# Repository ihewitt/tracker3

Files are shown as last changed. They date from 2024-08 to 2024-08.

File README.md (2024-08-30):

# Tracker III.2
A BG96 and NRF52840 based GPS tracker

The history for this design can be found on a series of posts: [Tracking running](https://blog.ivor.org/2020/10/tracking-running-part-2.html) [RAK track](https://blog.ivor.org/2022/02/between-rak-and-sweet-place.html) [Tracker two](https://blog.ivor.org/2022/03/trackertwo.html), the full details for this build are at [T3 Rise of the machines](https://blog.ivor.org/2024/08/t3-rise-of-machines.html)

Latest schematic [here](schematic.pdf), component layout [here](layout.pdf), Bill of materials [here](tracker-bom.csv)

Main functional features on the board are highlighted here:

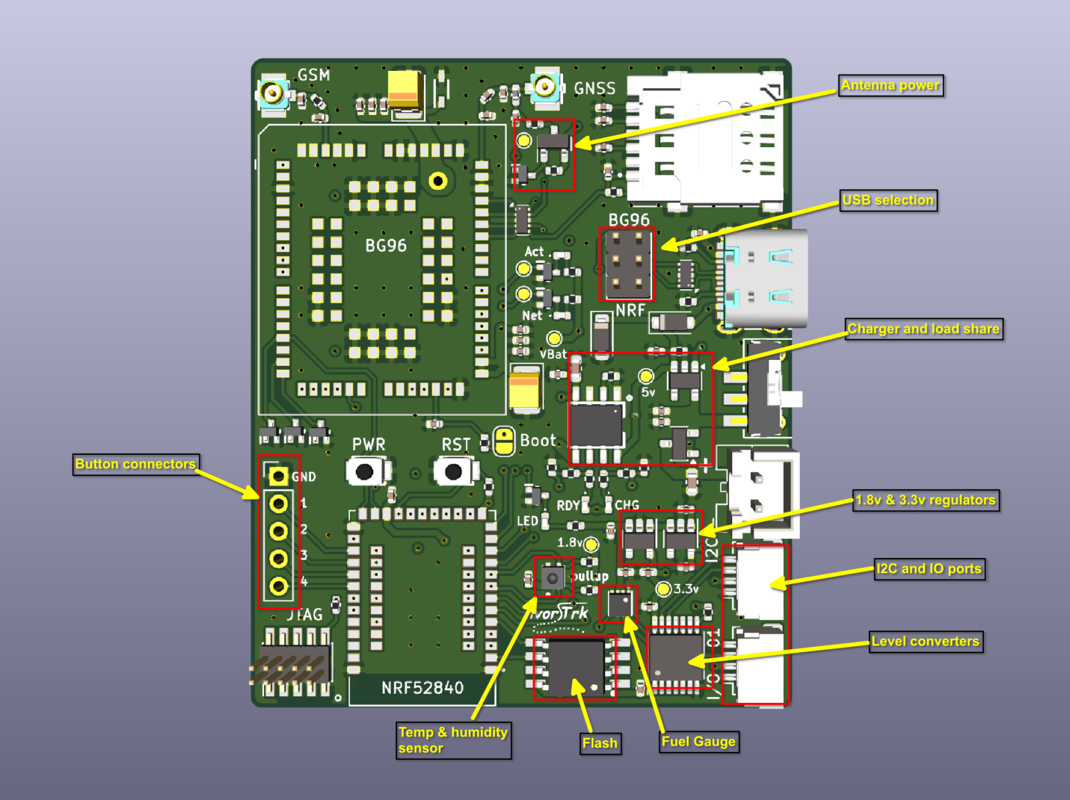
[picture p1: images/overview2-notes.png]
New PCB design


### USB connection
I changed to a USB-C connector, and the USB connection can be switched between the NRF and BG96 chips, most of the time the NRF will be useful but if you need/want to diagnose the GPS data directly or update the BG96 firmware then you can move jumpers.

### Charger
I changed the charger design to include a load share design and a power regulator with a "reverse current" protection shown on the schematic:

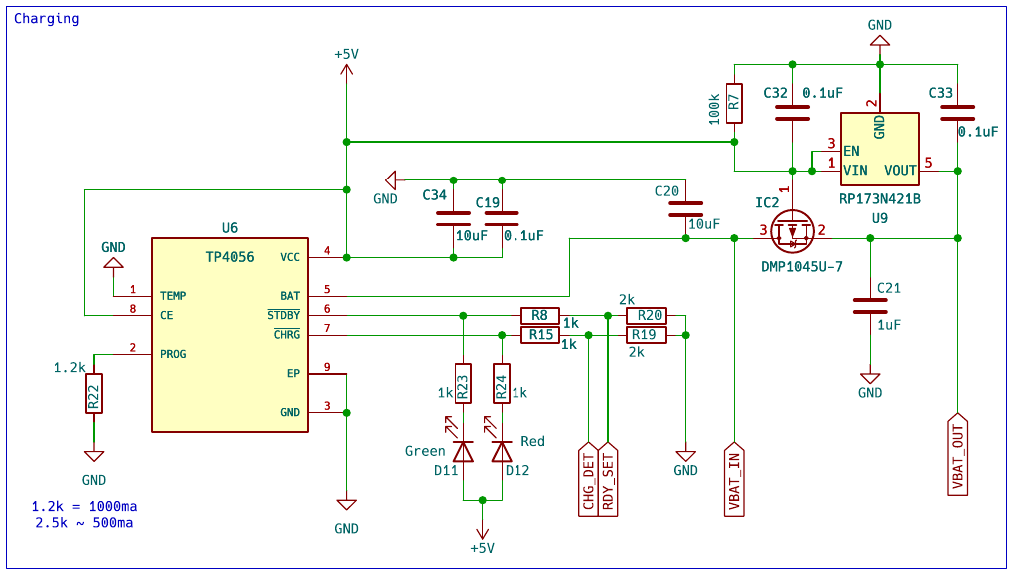
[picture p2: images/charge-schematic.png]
Charger schematic


When USB power is applied and the TP4056 starts charging, the MOSFET IC2 detaches the battery from the load and the power to the board is taken from the regulator U9.
When the USB power is removed and the battery (VBAT_IN) is the source then the MOSFET lets the power run through to VBAT_OUT directly, the reverse current protection on U9 prevents it returning to the 5v line.

### Regulators
The board internally runs all devices and data lines at 1.8v but level shifts these for external interfacing to 3.3v.

### IO Ports
Two qwiik compatible connectors provide 3.3v I2C and general purpose IO lines.

### Fuel Gauge
A MAX17048 fuel gauge chip is included to give an accurate and reliable power level info.

### Flash
Onboard 8Gb Flash module, I'm still on the fence whether to replace this with an SDcard slot instead.

### Temp & Humidity
Since I had a space on the board and it was next to the I2C lines, I changed my mind and decided to include a SHTC3 temperature and humidity chip. I found the temperature in tracker2 wasn't particularly useful so instead used an external ANT sensor, but the humidity was handy.

### Button connectors
Four GPIO lines are exposed alongside a ground line to make it easy to add a set of buttons.

# Render
The render view in KiCad is handy to check the layout looks sane and makes sense:

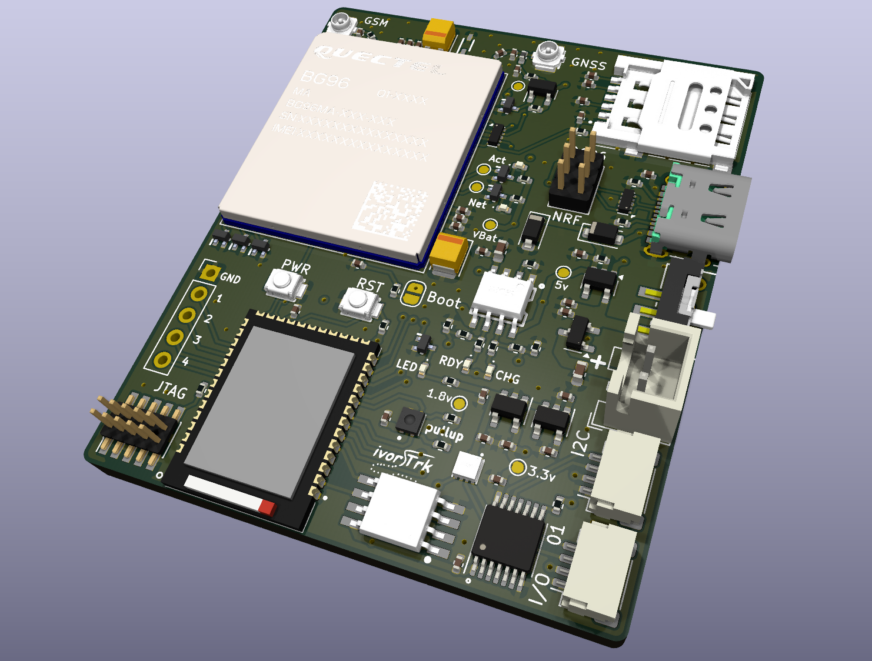
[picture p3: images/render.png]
3D render of board


A picture of a nearly final prototype up and running:

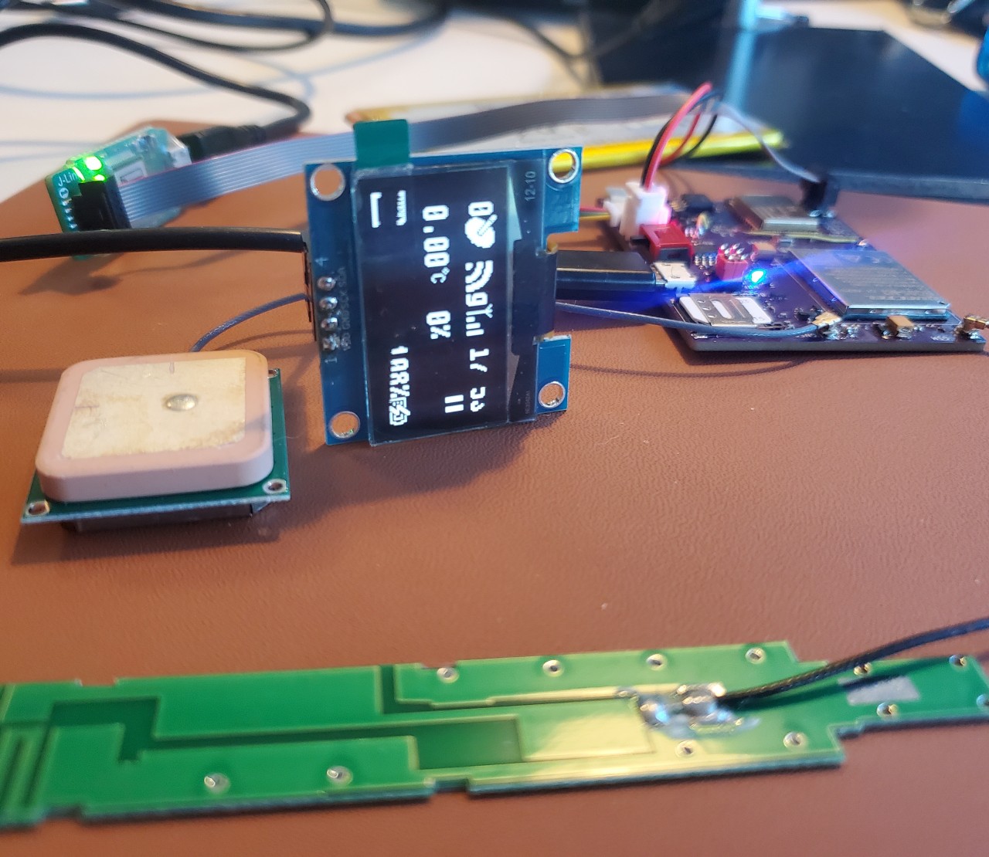
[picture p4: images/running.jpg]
Tracker running with display showing status


## Build Notes
The build is a single sided board so quite straightforward to manufacture, although there are a few options to make it simpler.

Firstly optional parts, the fuel gauge can be omitted just skip U4 and C17, the pull-ups are still needed though for working I2C.
Similarly the temperature sensor can be skipped, omit U10 and C35.
The flash isn't absolutely necessary, but it's an easy to solder part and it's really quite useful.
The entire charge circuit can be omitted if preferred and the battery charged externally, but again these aren't complicated parts to solder. 

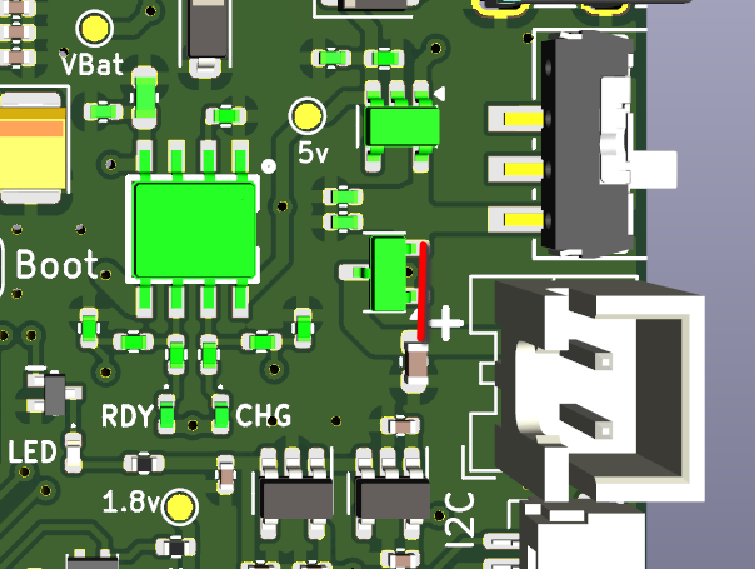
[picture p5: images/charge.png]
Charge closeup with green highlighted parts


Just skip the parts marked in green and connect VBAT_IN to VBAT_OUT (in red)

Another option is to use a BG95 instead of the BG96, since they are software and pin compatible, the BG95 was considerably cheaper for a while although prices seem to have returned to sanity now.
The downside of the BG95 is that it can't operate GPS and GSM simultaneously, not a huge issue with a 1 or 5 minute upload.

### Difficult parts
Next up, difficult parts to solder.... the fuel gauge U4, and the ESD's U2 and U5 have very close contacts, these can bridge even with hotplate soldering so need inspecting although the pins can be easily fixed with the touch of a fine soldering iron since the pins are visible at the edges. Similary the USB-C socket can be trouble and needs inspection.

### Soldering
It's a good idea to use low temperature solder since a full temperature reflow will also reflow the internals of the BG96 and Holyiot modules. Another possibility would be to get the board manufactured by someone else (or flowed yourself) in two stages, initially just all the components *except* the two modules using standard temperature solder. Then after the board is manufactured, apply low temp paste for the BG96 and Holyiot for a second low-temp reflow.

### Software
As a starting point the software for the "RAKtrack" can be used after changing the pin numbers (the Pin numbers for v3 are in [gpiopins.h](gpiopins.h)). When the IVRtrack code is polished I'll update and add to this github also. 

For RAK track, the website server software is [here](https://github.com/ihewitt/gps-server). and the firmware for the rak board is [here](https://github.com/ihewitt/raktrack).

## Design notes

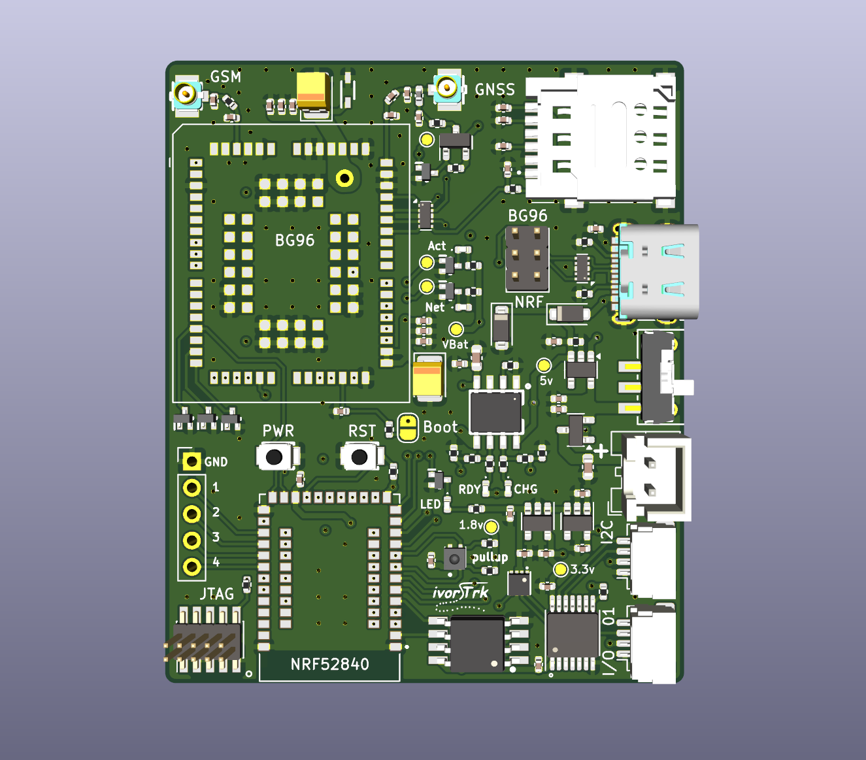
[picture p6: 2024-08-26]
images/overview2.png

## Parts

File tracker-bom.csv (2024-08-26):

Reference | Value | Qty | MRF | Digikey
ANT1,ANT2 | U.FL-R-SMT-1_10_ | 2 | U.FL-R-SMT(10) | H9161CT-ND
C1 | 4.7uF | 1 | GRM155R60J475ME47J | 490-GRM155R60J475ME47JCT-ND
C2 | 10nF | 1 | CC0402KRX7R6BB103 | 311-1703-1-ND
C3,C13,C14,C17,C18,C19,C29,C30,C31,C32,C33 | 0.1uF | 11 | CL10B104KB8NNWC | 1276-1935-1-ND
C4 | 100pF | 1 | CC0402JRNPO9BN101 | 311-1024-1-ND
C5,C6,C7,C11,C12 | 33pF | 5 | GRM1555C1H330JA01D | 490-5936-1-ND
C9,C10 | 10pF | 2 | GRM1555C1H100JA01D | 490-5921-1-ND
C15,C16 | 100uF | 2 | TAJA107K004RNJ | 478-8876-1-ND
C20,C34 | 10uF | 2 | CM105X5R106K16AT | 478-CM105X5R106K16ATCT-ND
C21,C22,C23,C24,C25 | 1uF | 5 | CL05A105KQ5NNNC | 1276-1010-1-ND
D1 | LED Orange | 1 | B2841UD--20D000614U1930 | 3147-B2841UD--20D000614U1930CT-ND
D2 | LED Blue | 1 | B2841NB--20C001414U1930 | 3147-B2841NB--20C001414U1930CT-ND
D3 | MBR140SFT1G | 1 | MBR140SFT1G | MBR140SFT1GOSTR-ND
D4 | LBZT52B5V6T1G | 1 | BZT52B5V6-HE3_A-08 | 112-BZT52B5V6-HE3_A-08TR-ND
D5,D12 | LED Red | 2 | B2841URO-20C001114U1930 | 3147-B2841URO-20C001114U1930CT-ND
D11 | Green | 1 | B1811NG--05D001013U1930 | 3147-B1811NG--05D001013U1930CT-ND
IC1 | IS25WP064A-JBLE | 1 | IS25WP064A-JBLE | 706-1590-ND
IC2 | DMP1045U-7 | 1 | DMP1045U-7 | DMP1045U-7DITR-ND
J2,J6 | I2C | 2 | SM04B-SRSS-TB | 455-SM04B-SRSS-TBCT-ND
J3 | JTAG | 1 | FTSH-105-01-F-DV | SAM8795-ND
J4 | SMN-305 | 1 | NSIM-2-C | 2223-NSIM-2-CCT-ND
J7 | BAT_CON | 1 | B02B-XASK-1N | 455-B02B-XASK-1N-ND
J9 | USBC | 1 | 12402012E212A | 664-12402012E212ATR-ND
JP2 | USB Select | 1 | PR20C03VBDN | 1849-1000-ND
L1 | 47nh | 1 | 7447860147 | 732-7447860147CT-ND
Q1,Q5,Q6,Q7,Q8,Q9 | DTC043ZEBTL | 6 | DTC043ZEBTL | DTC043ZEBTLCT-ND
Q10 | DTC143ZEBTL | 1 | DTC143ZEBTL | DTC143ZEBTLCT-ND
Q11 | IRLML6401 | 1 | IRLML6401TRPBF | IRLML6401PBFCT-ND
R1,R3,R4,R10,R16,R17 | 10k | 6 | RC0603FR-0710KL | 311-10.0KHRCT-ND
R2,R9,R12,R13 | 4.7k | 4 | RC0402FR-074K7L | 311-4.7KLRCT-ND
R5,R6 | 5.1k | 2 | ERJ-2GEJ512X | P5.1KJTR-ND
R7 | 100k | 1 | RC0402FR-07100KL | 311-100KLRTR-ND
R8,R15,R23,R24 | 1k | 4 | RC0402FR-071KL | 311-1.00KLRCT-ND
R11 | 10 | 1 | RC0402FR-0710RL | 311-10.0LRCT-ND
R14,R18 | 0 | 2 | RMCF0402ZT0R00 | RMCF0402ZT0R00CT-ND
R19,R20 | 2k | 2 | ERJ-2RKF2001X | P2.00KLTR-ND
R22 | 1.2k | 1 | RMCF0402JT1K20 | RMCF0402JT1K20CT-ND
SW1,SW2 | PWR,RESET | 2 | B3U-1000PM | 39-B3U-1000PMTR-ND
SW3 | SW_SPDT | 1 | CSS-1210TB | 563-1091-1-ND
U1 | HOLYIOT-18010 | 1
U2,U5 | D3V3XA4B10LP | 2 | D3V3XA4B10LP-7 | 31-D3V3XA4B10LP-7CT-ND
U3 | BG96 | 1
U4 | MAX17048 | 1 | MAX17048G+T10 | MAX17048G+T10TR-ND
U6 | TP4056 | 1
U7 | AP2127K-3.3 | 1 | AP2127K-3.3TRG1 | AP2127K-3.3TRG1DICT-ND
U8 | AP2127K-1.8 | 1 | AP2127K-1.8TRG1 | AP2127K-1.8TRG1DICT-ND
U9 | RP173N421B | 1 | RP173N421B-TR-FE | RP173N421B-TR-FE
U11 | TXS0104PWR | 1 | TXS0104EPWR | 296-20697-1-ND
Z1 | MM3Z5V1ST1G | 1 | MM3Z5V1ST1G | MM3Z5V1ST1GOSCT-ND

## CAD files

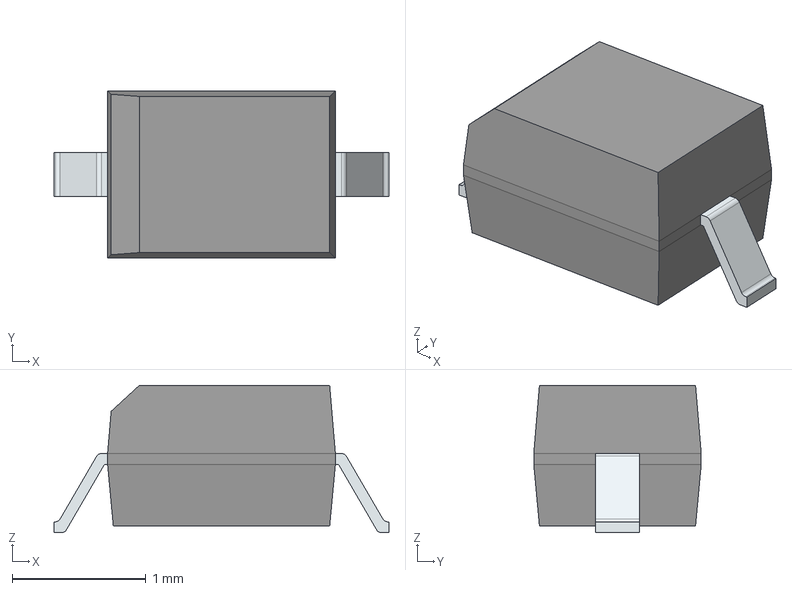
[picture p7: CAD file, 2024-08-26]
components/3D/MM3Z5V1ST1G.stp
2.50 x 1.25 x 1.10 mm
FilletPinL
FilletPinR

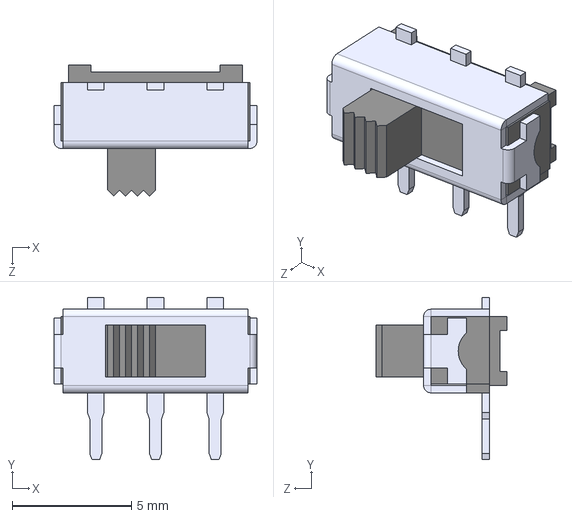
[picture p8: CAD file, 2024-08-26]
components/3D/EG1270.step
8.50 x 6.80 x 5.50 mm

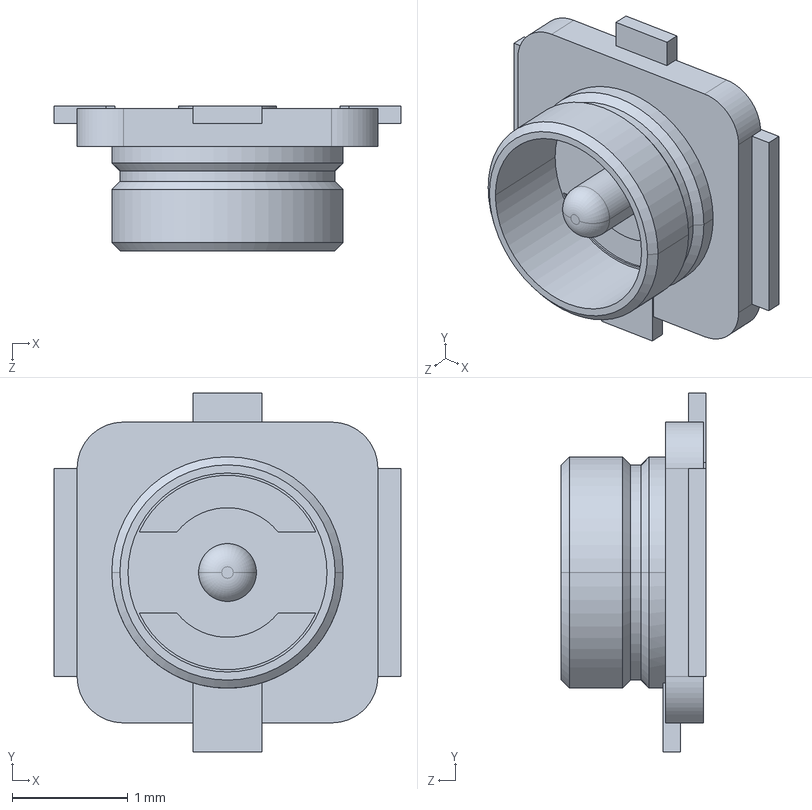
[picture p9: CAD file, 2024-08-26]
components/3D/U.FL-R-SMT-1_10_.stp
3.00 x 3.10 x 1.25 mm

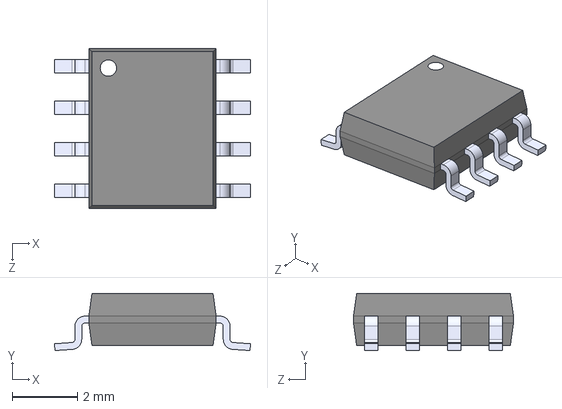
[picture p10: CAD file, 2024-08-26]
components/3D/TP4056.step
6.00 x 1.75 x 4.90 mm

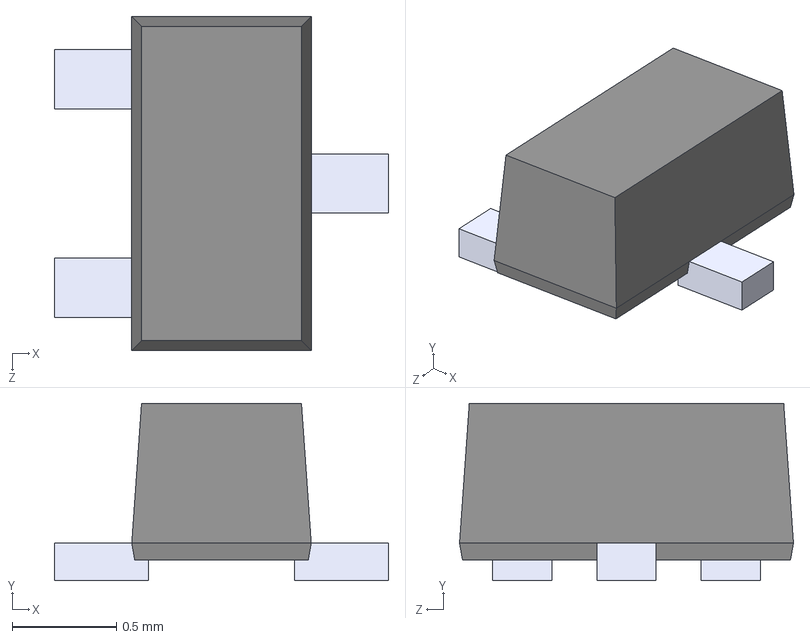
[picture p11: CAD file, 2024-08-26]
components/3D/DTC143ZEBTL--3DModel-STEP-56544.STEP
1.60 x 0.85 x 1.60 mm

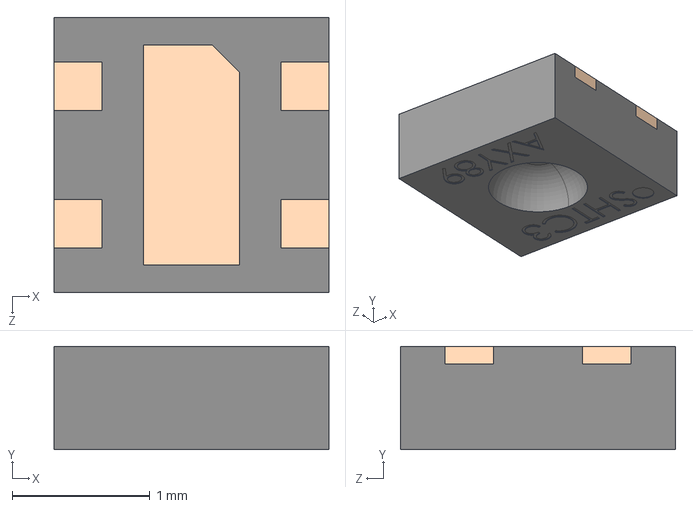
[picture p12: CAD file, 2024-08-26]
components/3D/SHTC3.stp
2.00 x 0.75 x 2.00 mm

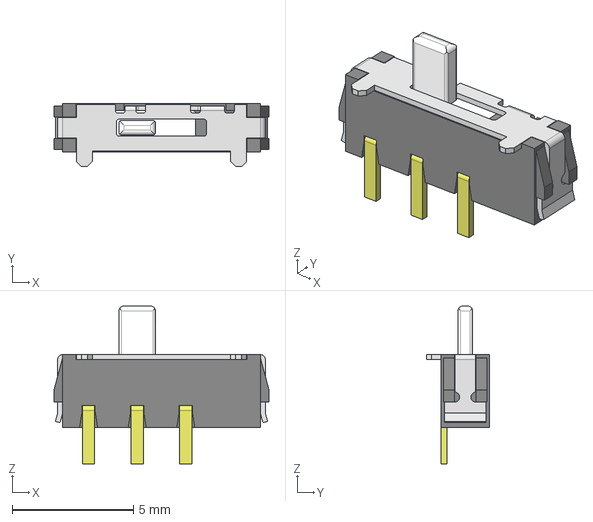
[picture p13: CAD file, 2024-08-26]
components/3D/CSS-1210TB.stp
8.85 x 2.60 x 6.50 mm
CSS-1210TB-b
CSS-1210TB-s

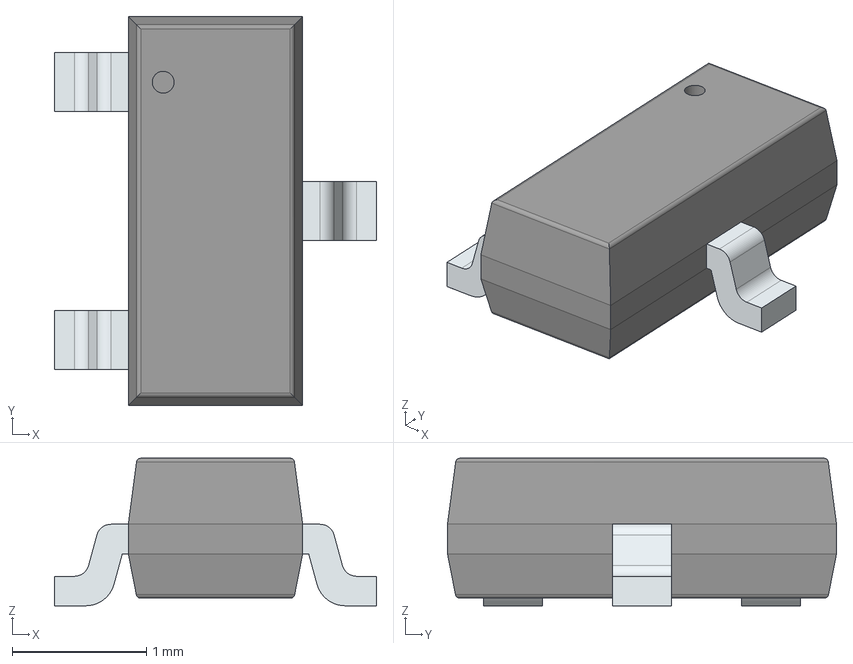
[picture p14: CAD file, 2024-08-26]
components/3D/DMP1045U-7.stp
2.40 x 2.90 x 1.10 mm
PinsArrayL
FilletPinR

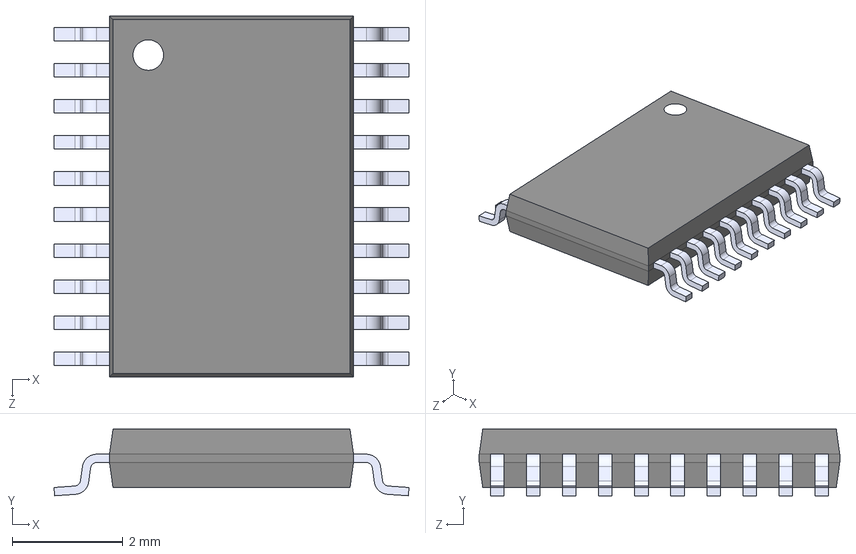
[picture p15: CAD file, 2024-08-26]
components/3D/TXB0108PWR.step
6.40 x 1.20 x 6.50 mm

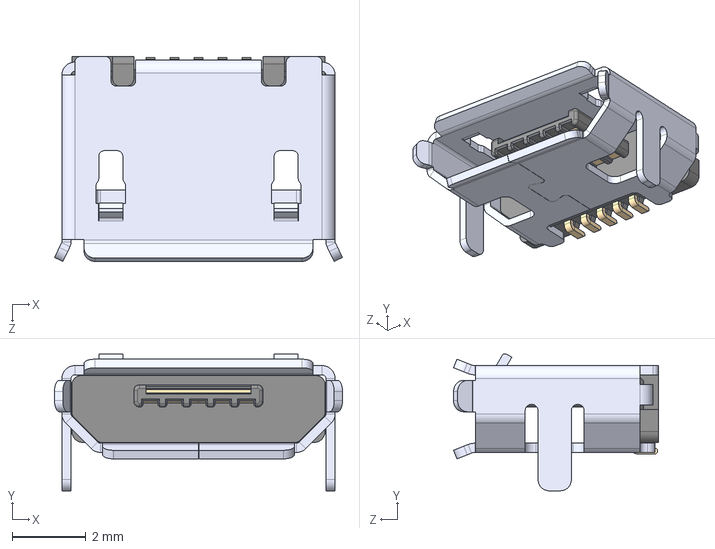
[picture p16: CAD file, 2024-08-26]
components/3D/USB3075-30-A.step
7.80 x 3.70 x 5.55 mm

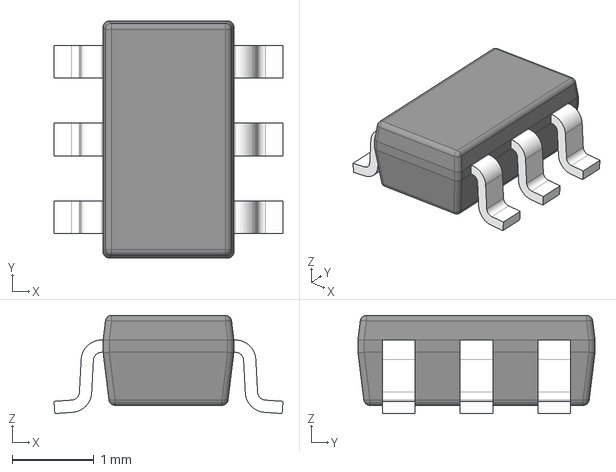
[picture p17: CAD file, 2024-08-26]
components/3D/BQ21040DBVR.stp
2.80 x 2.90 x 1.20 mm
BODY-SOT
LEAD-SOT x 6

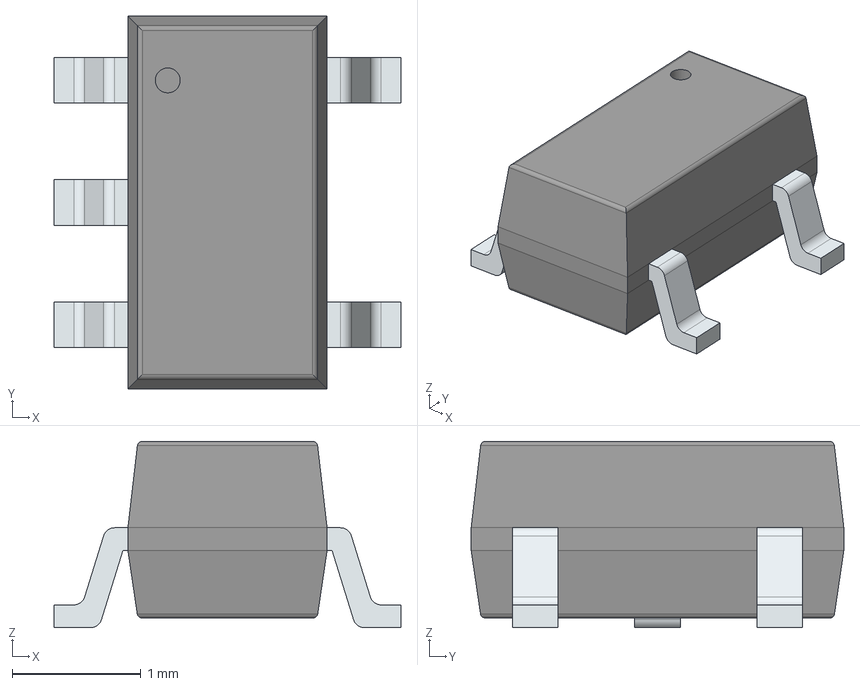
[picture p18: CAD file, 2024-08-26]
components/3D/MCP73832T-2ACI_OT.stp
2.70 x 2.90 x 1.45 mm
PinsArrayL
PinsArrayR

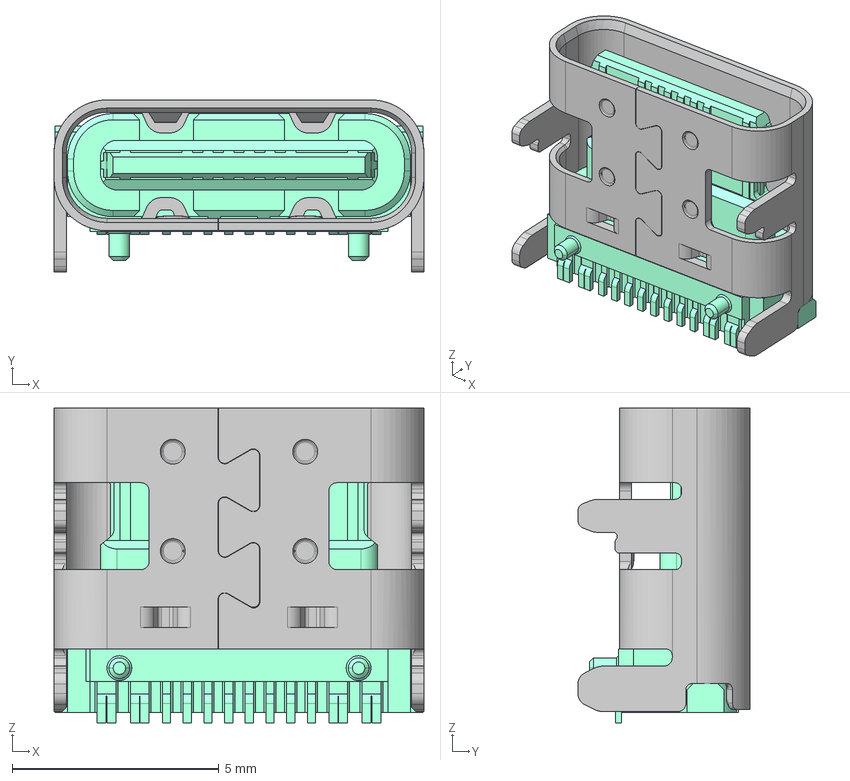
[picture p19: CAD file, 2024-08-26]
components/3D/12402012E212A.step
8.94 x 4.16 x 7.60 mm

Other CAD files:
components/3D/U.FL-R-SMT-1.step

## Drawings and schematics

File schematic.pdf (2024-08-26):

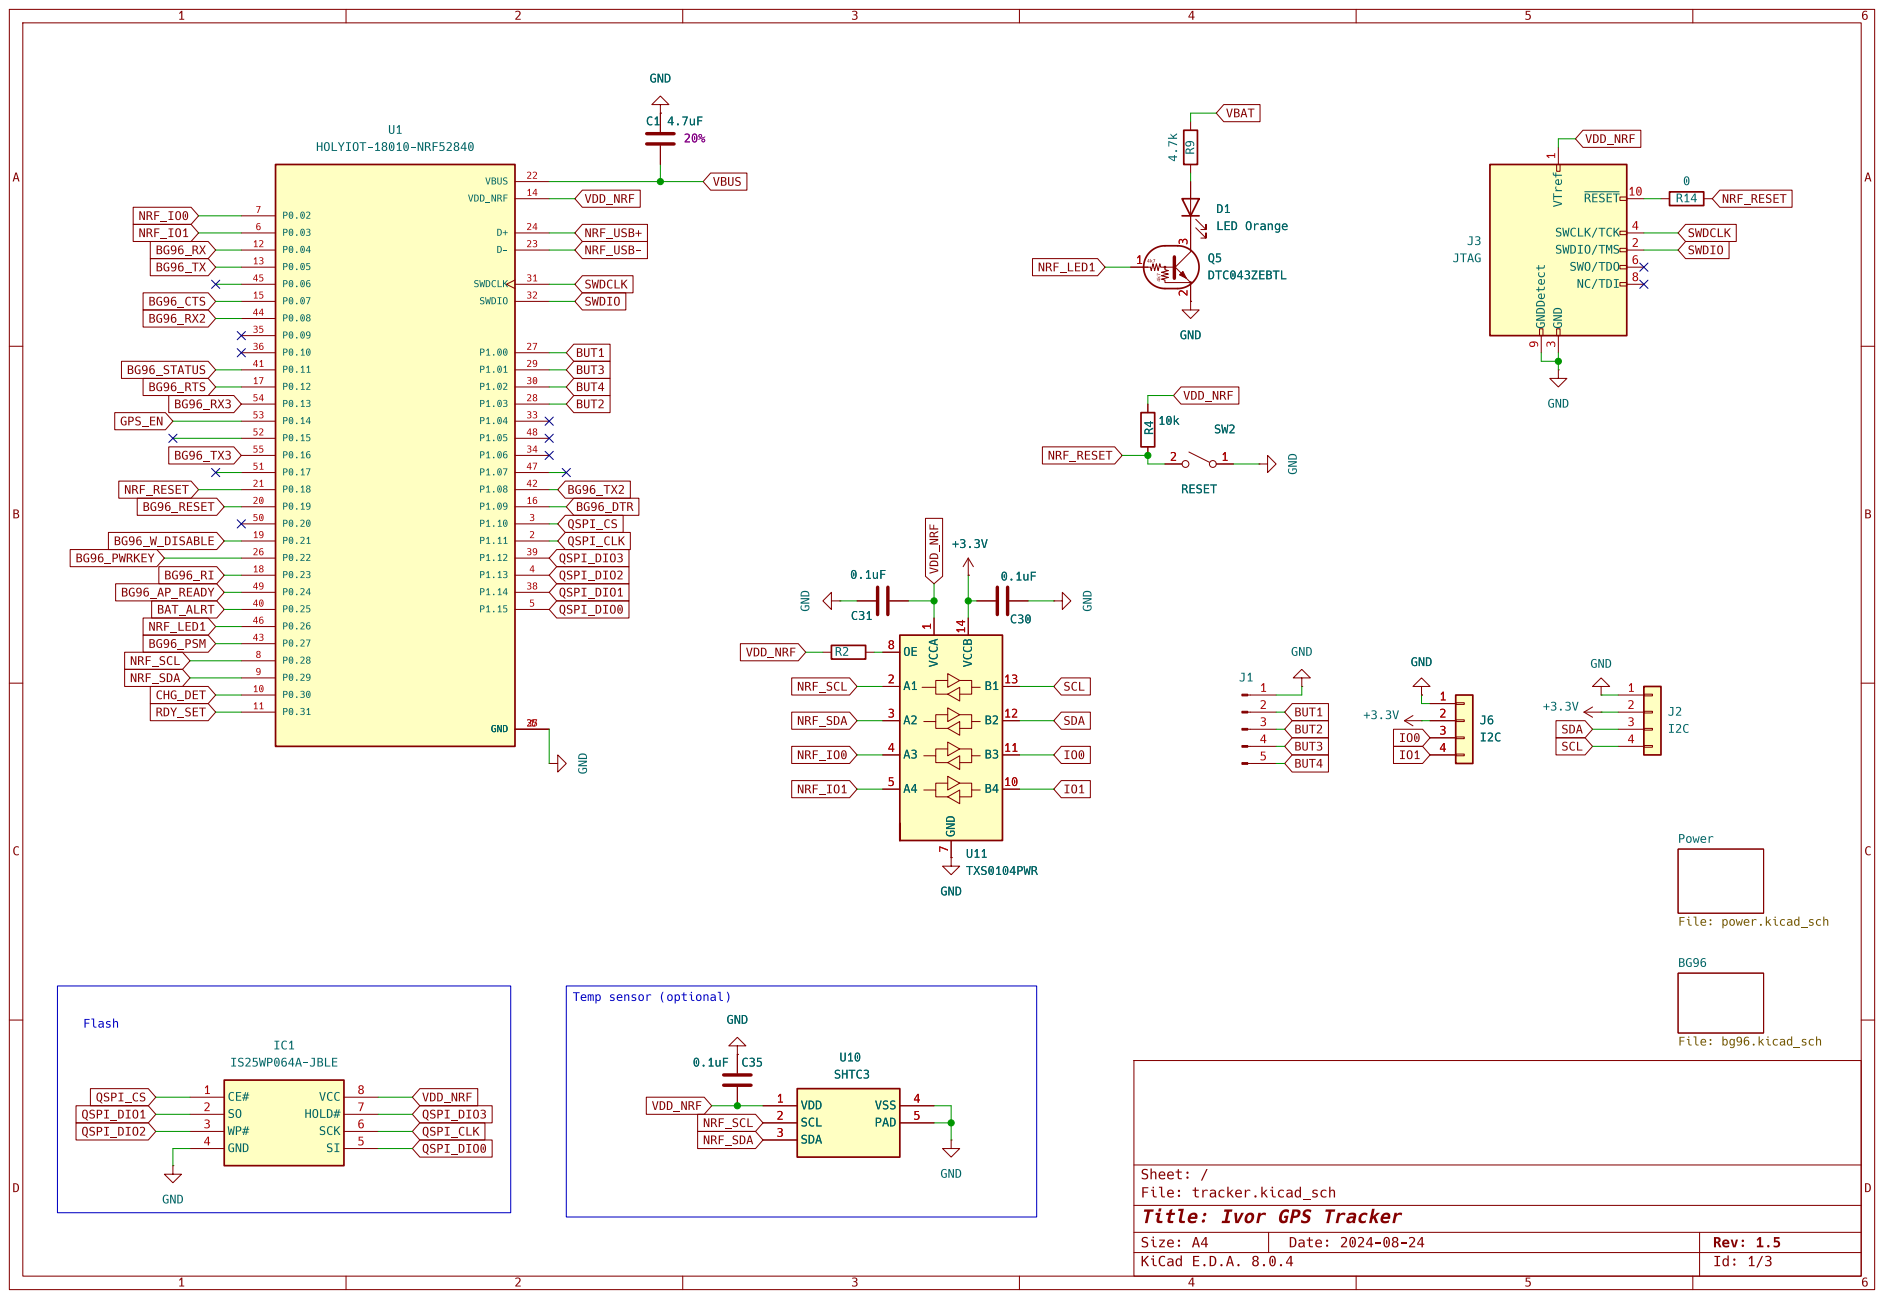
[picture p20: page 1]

2 3 Q5 DTC043ZEBTL GNDVTref 1 ~{RESET} 10 SWDIO/TMS

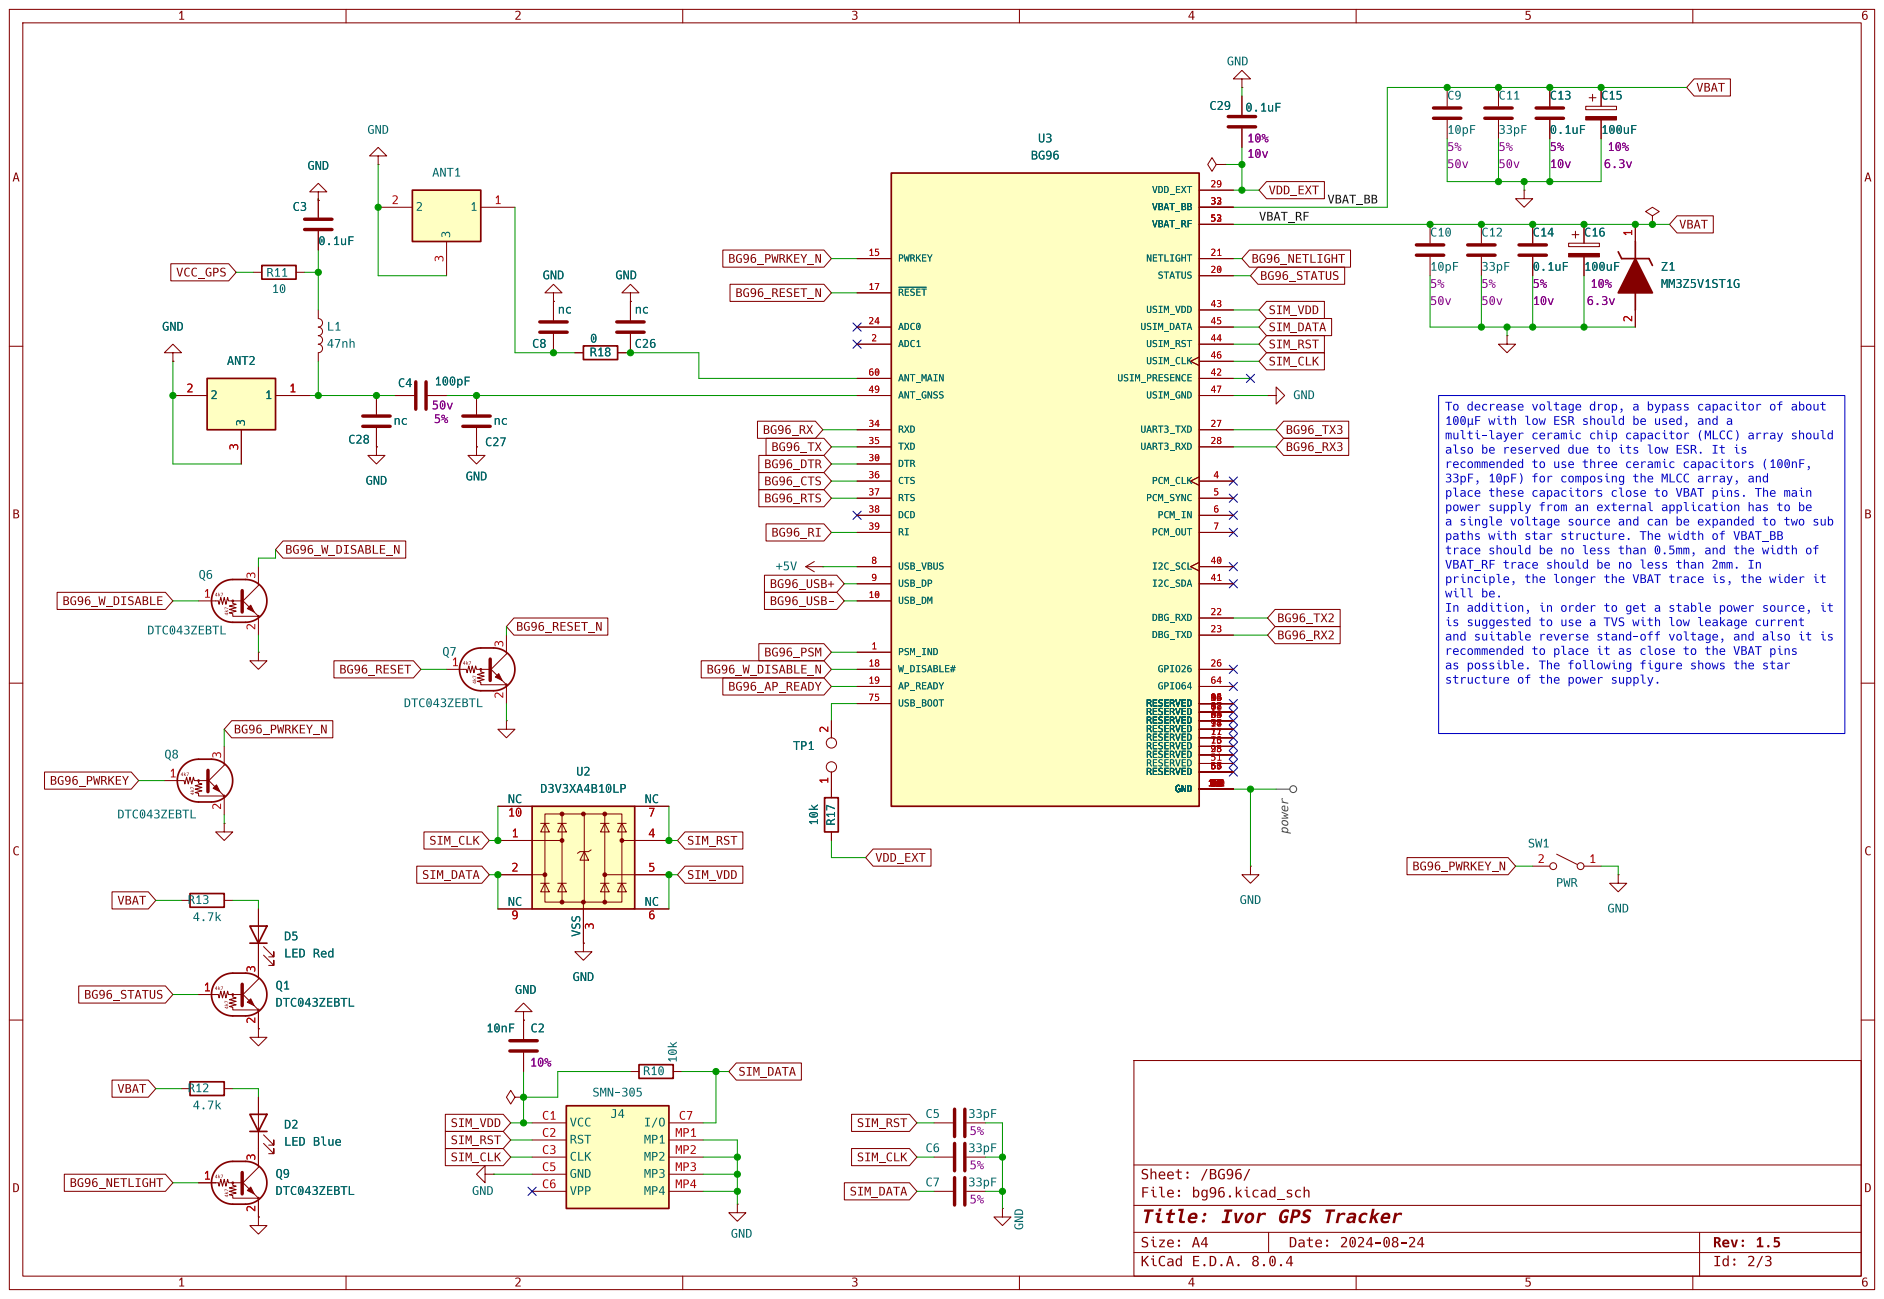
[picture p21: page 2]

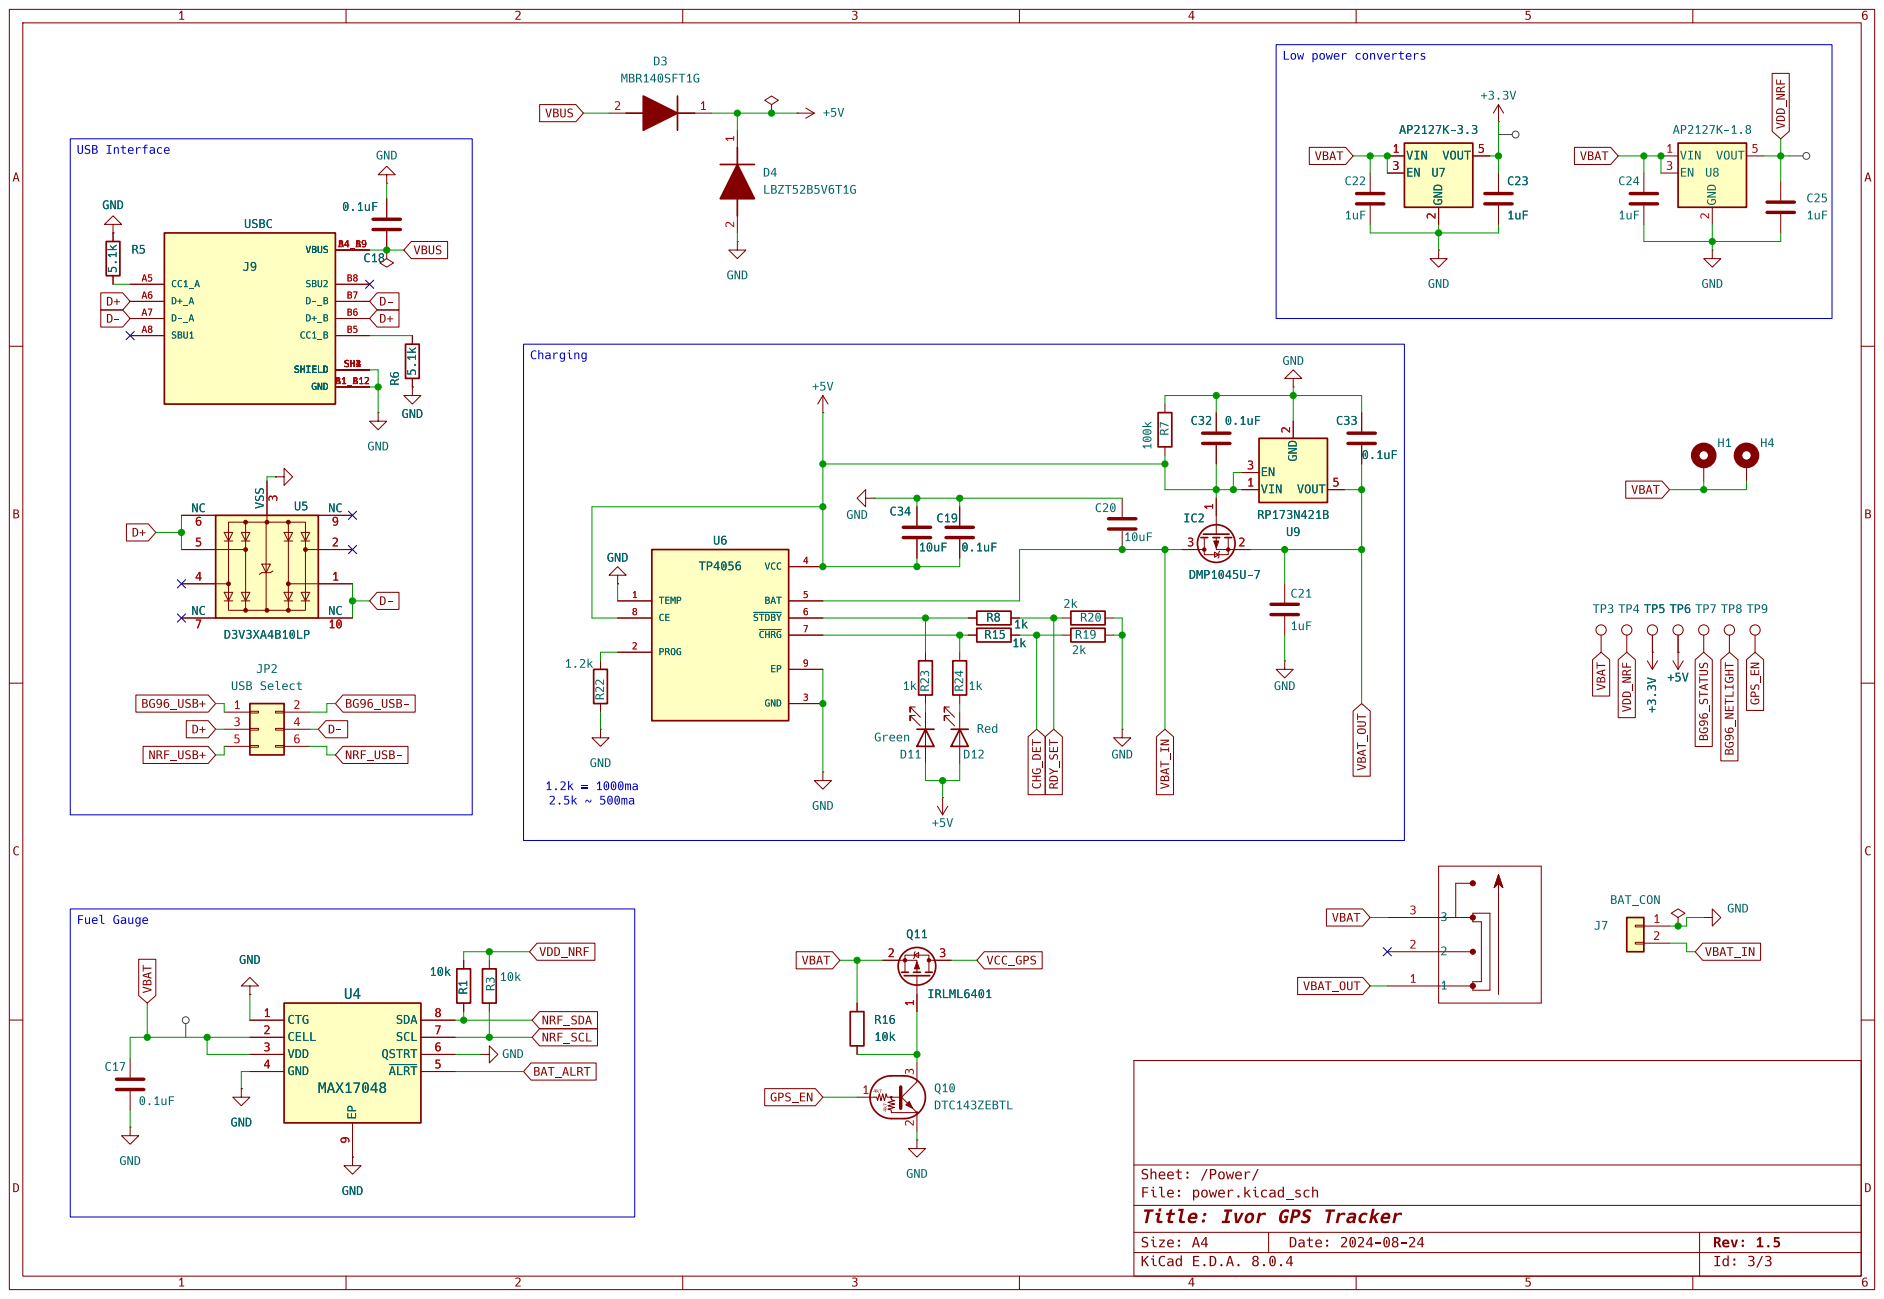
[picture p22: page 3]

1uF GND

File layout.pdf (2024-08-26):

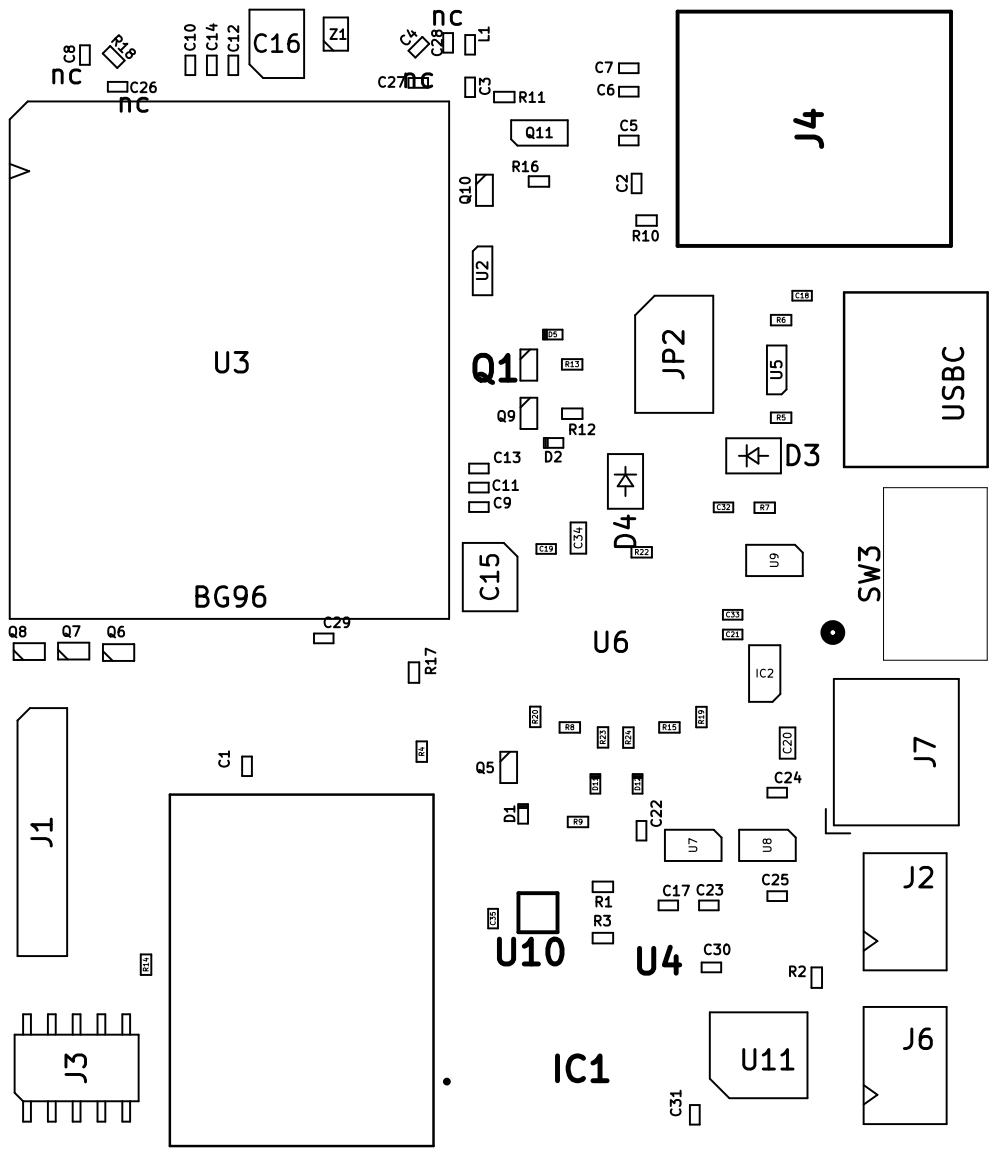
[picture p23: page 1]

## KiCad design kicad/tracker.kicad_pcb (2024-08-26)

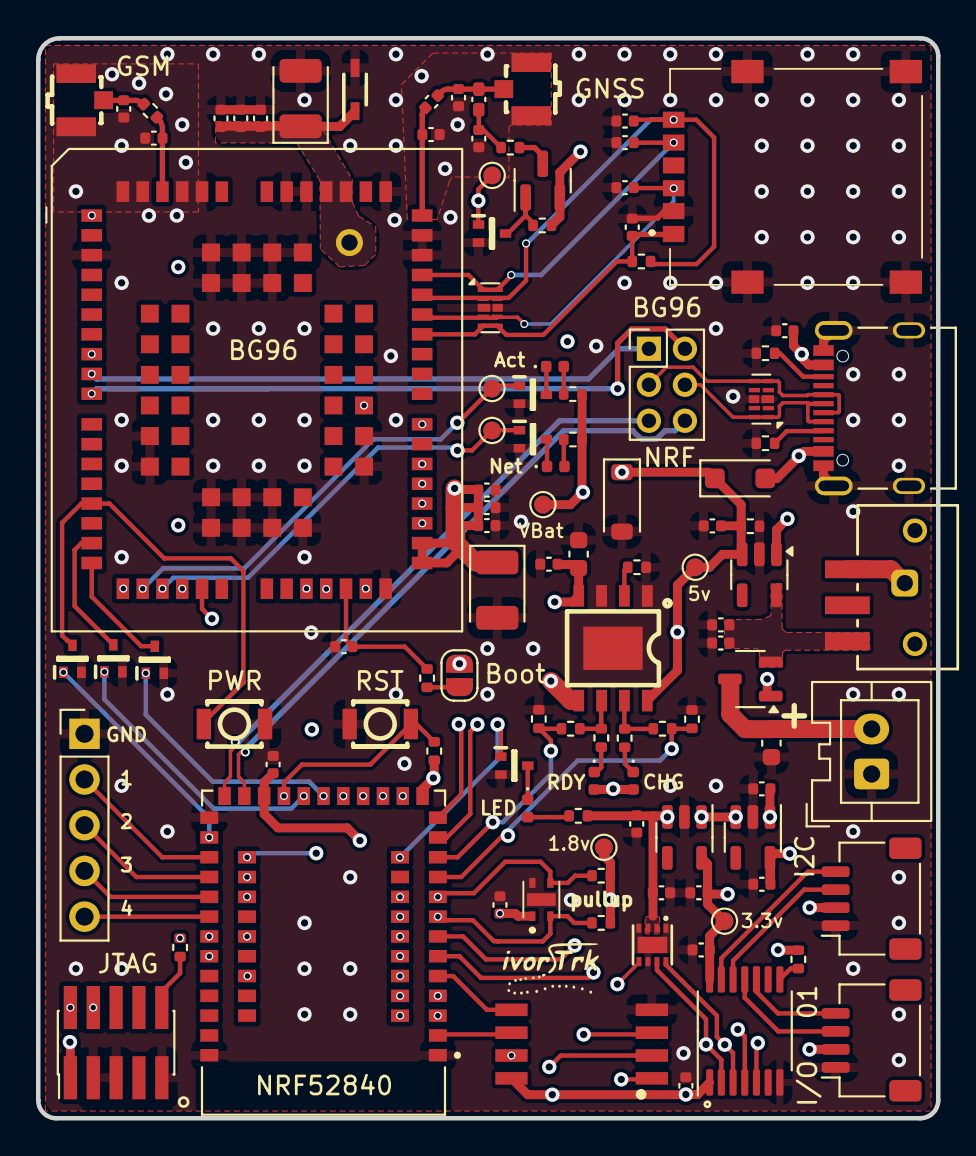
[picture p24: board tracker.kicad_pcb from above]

Board: 4 copper layers, 50.0 x 60.0 mm, 111 parts (0 on the bottom side), 89 nets.

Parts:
ANT1, ANT2: U.FL-R-SMT-1_10_; RF-SMD_FRF05002-JSS103M
C1: 4.7uF; C_0402_1005Metric
C2: 10nF; C_0402_1005Metric
C3, C13, C14, C17, C18, C19, C29, C30, C31, C32, C33, C35: 0.1uF; C_0402_1005Metric
C4: 100pF; C_0402_1005Metric
C5, C6, C7, C11, C12: 33pF; C_0402_1005Metric
C8, C26, C27, C28: nc; C_0402_1005Metric
C9, C10: 10pF; C_0402_1005Metric
C15, C16: 100uF; CP_EIA-3528-21_Kemet-B
C20, C34: 10uF; C_0603_1608Metric
C21, C22, C23, C24, C25: 1uF; C_0402_1005Metric
D1: LED Orange; LED_0402_1005Metric
D2: LED Blue; LED_0402_1005Metric
D3: MBR140SFT1G; D_SOD-123F
D4: LBZT52B5V6T1G; D_SOD-123
D5: LED Red; LED_0402_1005Metric
D11: Green; LED_0402_1005Metric
D12: Red; LED_0402_1005Metric
H1, H4: Pad
IC1: IS25WP064A-JBLE; SOIC-8_L5.3-W5.3-P1.27-LS7.9-BL
IC2: DMP1045U-7; SOT-23-3
J1: Conn_01x05_Pin; PinHeader_1x05_P2.54mm_Vertical
J2, J6: I2C; JST_SH_SM04B-SRSS-TB_1x04-1MP_P1.00mm_Horizontal
J3: JTAG; PinHeader_2x05_P1.27mm_Vertical_SMD
J4: SMN-305; SMN305
J7: BAT_CON; JST_XA_B02B-XASK-1_1x02_P2.50mm_Vertical
J9: USBC; 12402012E212A
JP2: USB Select; PinHeader_2x03_P2.00mm_Vertical
L1: 47nh; L_0402_1005Metric_Pad0.77x0.64mm_HandSolder
Q1, Q5, Q6, Q7, Q8, Q9: DTC043ZEBTL; SOTFL50P160X85-3N
Q10: DTC143ZEBTL; SOTFL50P160X85-3N
Q11: IRLML6401; SOT-23
R1, R3, R4, R10, R16, R17: 10k; R_0402_1005Metric
R2, R9, R12, R13: 4.7k; R_0402_1005Metric
R5, R6: 5.1k; R_0402_1005Metric
R7: 100k; R_0402_1005Metric
R8, R15, R23, R24: 1k; R_0402_1005Metric
R11: 10; R_0402_1005Metric
R14, R18: 0; R_0402_1005Metric
R19, R20: 2k; R_0402_1005Metric
R22: 1.2k; R_0402_1005Metric
SW1: PWR; KEY-SMD_B3U-1000PM
SW2: RESET; KEY-SMD_B3U-1000PM
SW3: SW_SPDT; SW3_CSS-1210TB_NDC
TP1: TestPoint_2Pole; SolderJumper-2_P1.3mm_Open_RoundedPad1.0x1.5mm
TP3, TP4, TP5, TP6, TP7, TP8, TP9: TestPoint; TestPoint_Pad_D1.0mm
U1: HOLYIOT-18010-NRF52840; XCVR_HOLYIOT-18010-NRF52840
U2, U5: D3V3XA4B10LP; Diodes_UDFN-10_1.0x2.5mm_P0.5mm
U3: BG96; Quectel_BG96
U4: MAX17048; DFN-8_L2.0-W2.0-P0.50-BL-EP
U6: TP4056; ESOP-8_L4.9-W3.9-P1.27-LS6.0-BL-EP
U7: AP2127K-3.3; SOT-23-5
U8: AP2127K-1.8; SOT-23-5
U9: RP173N421B; SOT-23-5
U10: SHTC3
U11: TXS0104PWR; TSSOP-14_4.4x5mm_P0.65mm
Z1: MM3Z5V1ST1G; SOD2512X110N

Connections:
+3.3V: C23.1, C30.1, J2.2, J6.2, TP5.1, U7.5 (VOUT), U11.14 (VCCB)
+5V: C19.2, C32.2, C34.1, D3.1 (K), D4.1 (K), D11.2 (A), D12.2 (A), IC2.1 (G), R7.1, TP6.1, U3.8 (USB_VBUS), U6.4 (VCC), U6.8 (CE), U9.1 (VIN), U9.3 (EN)
BAT_ALRT: U1.40 (P0.25), U4.5 (~ALRT)
BG96_AP_READY: U1.49 (P0.24), U3.19 (AP_READY)
BG96_CTS: U1.15 (P0.07), U3.36 (CTS)
BG96_DTR: U1.16 (P1.09), U3.30 (DTR)
BG96_NETLIGHT: Q9.1 (B), TP8.1, U3.21 (NETLIGHT)
BG96_PSM: U1.43 (P0.27), U3.1 (PSM_IND)
BG96_PWRKEY: Q8.1 (B), U1.26 (P0.22)
BG96_PWRKEY_N: Q8.3 (C), SW1.2 (B), U3.15 (PWRKEY)
BG96_RESET: Q7.1 (B), U1.20 (P0.19)
BG96_RESET_N: Q7.3 (C), U3.17 (~RESET)
BG96_RI: U1.18 (P0.23), U3.39 (RI)
BG96_RTS: U1.17 (P0.12), U3.37 (RTS)
BG96_RX: U1.12 (P0.04), U3.34 (RXD)
BG96_RX2: U1.44 (P0.08), U3.23 (DBG_TXD)
BG96_RX3: U1.54 (P0.13), U3.28 (UART3_RXD)
BG96_STATUS: Q1.1 (B), TP7.1, U1.41 (P0.11), U3.20 (STATUS)
BG96_TX: U1.13 (P0.05), U3.35 (TXD)
BG96_TX2: U1.42 (P1.08), U3.22 (DBG_RXD)
BG96_TX3: U1.55 (P0.16), U3.27 (UART3_TXD)
BG96_USB+: JP2.1, U3.9 (USB_DP)
BG96_USB-: JP2.2, U3.10 (USB_DM)
BG96_W_DISABLE: Q6.1 (B), U1.19 (P0.21)
BG96_W_DISABLE_N: Q6.3 (C), U3.18 (W_DISABLE#)
BUT1: J1.2, U1.27 (P1.00)
BUT2: J1.3, U1.28 (P1.03)
BUT3: J1.4, U1.29 (P1.01)
BUT4: J1.5, U1.30 (P1.02)
CHG_DET: R15.2, R19.1, U1.10 (P0.30)
D+: J9.A6 (D+_A), J9.B6 (D+_B), JP2.3, U5.5, U5.6 (NC)
D-: J9.A7 (D-_A), J9.B7 (D-_B), JP2.4, U5.1, U5.10 (NC)
GND: ANT1.2, ANT1.3, ANT2.2, ANT2.3, C1.2, C2.2, C3.1, C5.1, C6.1, C7.1, C8.1, C9.2, C10.2, C11.2, C12.2, C13.2, C14.2, C15.2, C16.2, C17.2, C18.2, C19.1, C20.1, C21.2, C22.2, C23.2, C24.2, C25.2, C26.1, C27.2, C28.2, C29.1, C30.2, C31.1, C32.1, C33.1, C34.2, C35.2, D4.2 (A), IC1.4 (GND), J1.1, J2.1, J3.3 (GND), J3.5 (GND), J3.9 (GNDDetect), J4.C5 (GND), J4.MP1, J4.MP2, J4.MP3, J4.MP4, J6.1, J7.1, J9.A1_B12 (GND), J9.B1_A12 (GND), J9.SH1 (SHIELD), J9.SH2 (SHIELD), J9.SH3 (SHIELD), J9.SH4 (SHIELD), Q1.2 (E), Q5.2 (E), Q6.2 (E), Q7.2 (E), Q8.2 (E), Q9.2 (E), Q10.2 (E), R5.2, R6.2, R7.2, R19.2, R20.2, R22.2, SW1.1 (A), SW2.1 (A), U1.1 (GND), U1.25 (GND), U1.37 (GND), U2.3 (VSS), U2.8 (VSS), U3.3 (GND), U3.31 (GND), U3.47 (USIM_GND), U3.48 (GND), U3.50 (GND), U3.54 (GND), U3.55 (GND), U3.58 (GND), U3.59 (GND), U3.61 (GND), U3.62 (GND), U3.67 (GND), U3.68 (GND), U3.69 (GND), U3.70 (GND), U3.71 (GND), U3.72 (GND), U3.73 (GND), U3.74 (GND), U3.79 (GND), U3.80 (GND), U3.81 (GND), U3.82 (GND), U3.89 (GND), U3.90 (GND), U3.91 (GND), U3.100 (GND), U3.101 (GND), U3.102 (GND), U4.1 (CTG), U4.4 (GND), U4.6 (QSTRT), U4.9 (EP), U5.3 (VSS), U5.8 (VSS), U6.1 (TEMP), U6.3 (GND), U6.9 (EP), U7.2 (GND), U8.2 (GND), U9.2 (GND), U10.4 (VSS), U10.5 (PAD), U11.7 (GND), Z1.2 (A)
GPS_EN: Q10.1 (B), TP9.1, U1.53 (P0.14)
IO0: J6.3, U11.11 (B3)
IO1: J6.4, U11.10 (B4)
NRF_IO0: U1.7 (P0.02), U11.4 (A3)
NRF_IO1: U1.6 (P0.03), U11.5 (A4)
NRF_LED1: Q5.1 (B), U1.46 (P0.26)
NRF_RESET: R4.2, R14.2, SW2.2 (B), U1.21 (P0.18)
NRF_SCL: R3.2, U1.8 (P0.28), U4.7 (SCL), U10.2 (SCL), U11.2 (A1)
NRF_SDA: R1.2, U1.9 (P0.29), U4.8 (SDA), U10.3 (SDA), U11.3 (A2)
NRF_USB+: JP2.5, U1.24 (D+)
NRF_USB-: JP2.6, U1.23 (D-)
unnamed: ANT1.1, C8.2, R18.1
unnamed: ANT2.1, C4.1, C28.1, L1.2
unnamed: C3.2, L1.1, R11.1
unnamed: D1.2 (A), R9.1
unnamed: D1.1 (K), Q5.3 (C)
unnamed: D2.2 (A), R12.1
unnamed: D2.1 (K), Q9.3 (C)
unnamed: D5.2 (A), R13.1
unnamed: D5.1 (K), Q1.3 (C)
unnamed: D11.1 (K), R23.2
unnamed: D12.1 (K), R24.2
unnamed: J3.10 (~RESET), R14.1
unnamed: J9.A5 (CC1_A), R5.1
unnamed: J9.B5 (CC1_B), R6.1
unnamed: Q10.3 (C), Q11.1 (G), R16.2
unnamed: R17.2, TP1.1
unnamed: C4.2, C27.1, U3.49 (ANT_GNSS)
unnamed: C26.2, R18.2, U3.60 (ANT_MAIN)
unnamed: TP1.2, U3.75 (USB_BOOT)
unnamed: R22.1, U6.2 (PROG)
unnamed: R15.1, R24.1, U6.7 (~CHRG)
unnamed: R8.1, R23.1, U6.6 (~STDBY)
unnamed: R2.1, U11.8 (OE)
QSPI_CLK: IC1.6 (SCK), U1.2 (P1.11)
QSPI_CS: IC1.1 (CE#), U1.3 (P1.10)
QSPI_DIO0: IC1.5 (SI), U1.5 (P1.15)
QSPI_DIO1: IC1.2 (SO), U1.38 (P1.14)
QSPI_DIO2: IC1.3 (WP#), U1.4 (P1.13)
QSPI_DIO3: IC1.7 (HOLD#), U1.39 (P1.12)
RDY_SET: R8.2, R20.1, U1.11 (P0.31)
SCL: J2.4, U11.13 (B1)
SDA: J2.3, U11.12 (B2)
SIM_CLK: C6.2, J4.C3 (CLK), U2.1, U2.10 (NC), U3.46 (USIM_CLK)
SIM_DATA: C7.2, J4.C7 (I/O), R10.2, U2.2, U2.9 (NC), U3.45 (USIM_DATA)
SIM_RST: C5.2, J4.C2 (RST), U2.4, U2.7 (NC), U3.44 (USIM_RST)
SIM_VDD: C2.1, J4.C1 (VCC), R10.1, U2.5, U2.6 (NC), U3.43 (USIM_VDD)
SWDCLK: J3.4 (SWCLK/TCK), U1.31 (SWDCLK)
SWDIO: J3.2 (SWDIO/TMS), U1.32 (SWDIO)
VBAT: C9.1, C10.1, C11.1, C12.1, C13.1, C14.1, C15.1, C16.1, C17.1, C22.1, C24.1, H1.1, H4.1, Q11.2 (S), R9.2, R12.2, R13.2, R16.1, SW3.3, TP3.1, U3.32 (VBAT_BB), U3.33 (VBAT_BB), U3.52 (VBAT_RF), U3.53 (VBAT_RF), U4.2 (CELL), U4.3 (VDD), U7.1 (VIN), U7.3 (EN), U8.1 (VIN), U8.3 (EN), Z1.1 (K)
VBAT_IN: C20.2, IC2.3 (D), J7.2, U6.5 (BAT)
VBAT_OUT: C21.1, C33.2, IC2.2 (S), SW3.1, U9.5 (VOUT)
VBUS: C1.1, C18.1, D3.2 (A), J9.A4_B9 (VBUS), J9.B4_A9 (VBUS), U1.22 (VBUS)
VCC_GPS: Q11.3 (D), R11.2
VDD_EXT: C29.2, R17.1, U3.29 (VDD_EXT)
VDD_NRF: C25.1, C31.2, C35.1, IC1.8 (VCC), J3.1 (VTref), R1.1, R2.2, R3.1, R4.1, TP4.1, U1.14 (VDD_NRF), U8.5 (VOUT), U10.1 (VDD), U11.1 (VCCA)

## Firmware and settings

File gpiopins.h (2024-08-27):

#define LED_PIN         NRF_GPIO_PIN_MAP(0, 26)
#define CHG_DET         NRF_GPIO_PIN_MAP(0, 30) // TP4056 CHRG
#define BAT_RDY         NRF_GPIO_PIN_MAP(0, 31) // TP4056 STDBY
#define BAT_ALRT        NRF_GPIO_PIN_MAP(0, 25) // Fuel Gauge ALRT
#define BUT1            NRF_GPIO_PIN_MAP(1, 0)
#define BUT2            NRF_GPIO_PIN_MAP(1, 3)
#define BUT3            NRF_GPIO_PIN_MAP(1, 1)
#define BUT4            NRF_GPIO_PIN_MAP(1, 2)
#define PIN_IO0         NRF_GPIO_PIN_MAP(0, 2)  // Qwiic 2
#define PIN_IO1         NRF_GPIO_PIN_MAP(0, 3)
#define SCL_PIN         NRF_GPIO_PIN_MAP(0, 28) // Qwiic 1
#define SDA_PIN         NRF_GPIO_PIN_MAP(0, 29)

#define GPS_TX2_PIN     NRF_GPIO_PIN_MAP(1, 8)
#define GPS_RX2_PIN     NRF_GPIO_PIN_MAP(0, 8)
#define GPS_TX3_PIN     NRF_GPIO_PIN_MAP(0, 16) // GPS stream
#define GPS_RX3_PIN     NRF_GPIO_PIN_MAP(0, 13)
#define GPS_TXD_PIN     NRF_GPIO_PIN_MAP(0, 5)  // GSM io 
#define GPS_RXD_PIN     NRF_GPIO_PIN_MAP(0, 4)
#define GPS_CTS_PIN     NRF_GPIO_PIN_MAP(0, 7)
#define GPS_RTS_PIN     NRF_GPIO_PIN_MAP(0, 12)

#define GSM_EN_PIN      NRF_GPIO_PIN_MAP(0, 14) // antenna power
#define GSM_RESET_PIN   NRF_GPIO_PIN_MAP(0, 19)
#define GSM_PWRKEY_PIN  NRF_GPIO_PIN_MAP(0, 22)
#define GSM_DISABLE_PIN NRF_GPIO_PIN_MAP(0, 21) // aka airplane mode
#define GSM_STATUS      NRF_GPIO_PIN_MAP(0, 11)
#define GSM_AP_READY    NRF_GPIO_PIN_MAP(0, 24)

#define PIN_RESET       NRF_GPIO_PIN_MAP(0, 18) // nrf reset line 

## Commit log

2024-08-26 Initial upload
    [12402012E212A.step, BQ21040DBVR.stp, CSS-1210TB.stp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]
2024-08-26 Add pcb layout
2024-08-26 Add BOM file with digikey references
    [tracker-bom.csv]
2024-08-27 Added gpio pin info and bg95 comments

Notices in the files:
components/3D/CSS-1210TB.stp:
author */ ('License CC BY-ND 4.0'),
